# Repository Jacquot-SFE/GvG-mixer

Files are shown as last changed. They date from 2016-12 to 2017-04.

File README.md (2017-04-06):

The Gort Vs Goom IEM Mixer.
========================================



Read more about it in [my blog post](https://www.sparkfun.com/news/2352)

Repository Contents
-------------------

* **/Datasheets** - Data sheets for the ICs & other components.
* **/Eagle** - PCB files
* **/Spice** - Simulations of the baxandall and peak hold circuits.
* **/Block-diagram** - Poorly named.  Various vector art, including a block diagram, and panel files.

Documentation
----

Ideas mainly pulled from Doug Self's _Small Signal Audio Design_ book, with other input from datasheets and appnotes from THAT, Jensen, and Nat Semi.

License Information
-------------------

This product is _**open source**_!

Please review the LICENSE.md file for license information.

If you have any questions or concerns on licensing, please contact techsupport@sparkfun.com.

Distributed as-is; no warranty is given.

- Your friends at SparkFun.

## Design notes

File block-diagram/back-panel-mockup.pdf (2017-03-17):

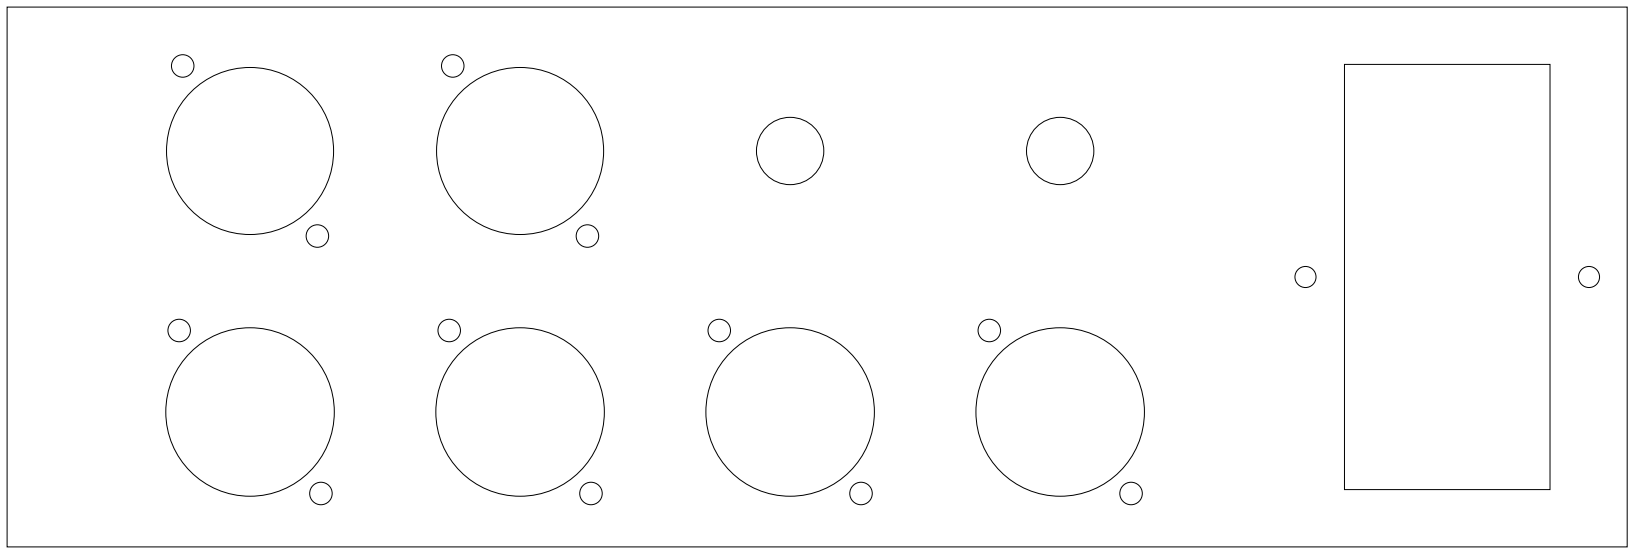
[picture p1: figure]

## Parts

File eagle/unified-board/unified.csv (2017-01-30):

Qty | MOUSER | Value | Device | Package | Parts | Description | MFR | PROD_ID | SF_ID | VALUE
14 | 505-MKS20.01/63/5 | 0.01uf | WIMA-MKS20.01UF | WIMA-MKS2-2.5X7.2 | C1, C2, C121, C122, C221, C222, C321, C322, C421, C422, C503, C504, C603, C604 |  |  |  |  | 0.01uf
8 | 80-C315C470J5G | 47pf | CAP-CERAMIC47PF | CAP-KEMET-GM-2.54LS | C101, C102, C201, C202, C301, C302, C401, C402 |  |  |  |  | 47pf
24 | 80-C315C471J1G | 470pf | CAP-CERAMIC470PF | CAP-KEMET-GM-2.54LS | C103, C104, C105, C106, C112, C113, C203, C204, C205, C206, C212, C213, C303, C304, C305, C306, C312, C313, C403, C404, C405, C406, C412, C413 |  |  |  |  | 470pf
8 | 667-EEU-FR1J470B | 47u/63V | CAP-LYTIC47U/63V | CAP-PANA-5LS-6DIAM | C107, C108, C207, C208, C307, C308, C407, C408 |  |  |  |  | 47u/63V
18 | 667-EEU-FR1E470B | 47u/25V | CAP-LYTIC47U/25V | CAP-PANA-5LS-5DIAM | C109, C110, C114, C120, C209, C210, C214, C220, C309, C310, C314, C320, C409, C410, C414, C420, C502, C602 |  |  |  |  | 47u/25V
4 | 667-EEU-FR1A682L | 6800u/25V | CAP-LYTIC6800U/10V | CAP-PANA-5LS-12.5DIAM | C111, C211, C311, C411 |  |  |  |  | 6800u/25V
8 | 505-MKS2.1/63/5 | 0.1uf | WIMA-MKS20.1UF | WIMA-MKS2-2.5X7.2 | C115, C116, C215, C216, C315, C316, C415, C416 |  |  |  |  | 0.1uf
8 | 505-MKS20.015/63/5 | 0.015uf | WIMA-MKS20.015UF | WIMA-MKS2-2.5X7.2 | C117, C118, C217, C218, C317, C318, C417, C418 |  |  |  |  | 0.015uf
8 | 80-C315C101J5G | 100pf | CAP-CERAMIC100PF | CAP-KEMET-GM-2.54LS | C119, C219, C319, C419, C501, C505, C601, C605 |  |  |  |  | 100pf
4 | 667-ECA-2CHG010 | 1uf/160V | CAP-LYTIC1UF/160V | CAP-PANA-2.5LS-6DIAM | C3, C4, C5, C6 |  |  |  |  | 1uf/160V
2 | 667-EEU-FR1V102 | 1000u/35V | CAP-LYTIC1000U/35V | CAP-PANA-5LS-12.5DIAM | C701, C702 |  |  |  |  | 1000u/35V
4 | sfe | 1n4148 | DIODE-1N4148 | DIODE-1N4148 | D1, D2, D3, D4 | Diode |  | DIO-08378 |  | 200mA/100V/1V
6 | 583-RB153 | RECTIFIERRB15X | RECTIFIERRB15X | SM-RECTIFIER | D101, D201, D301, D401, D501, D601
8 | sfe | 200mA/100V/1V | DIODE-1N4148 | DIODE-1N4148 | D102, D103, D202, D203, D302, D303, D402, D403 | Diode |  | DIO-08378 |  | 200mA/100V/1V
2 | sfe | RED | LED_BARGRAPH_10RED | LED_BARGRAPH_10 | D502, D602 | Young Sun LED Tech - YSLB-10251G5-10 10-Segment LED Bar Graph |  | DIO-10615 |  | RED
1 | sfe |  | LED5MM | LED_5MM | D701 | LED (Generic)
2 | 623-2743002112LF | FB | FB | BEAD | FB501, FB601 |  |  |  |  | FB
7 | na | FRAME-LEDGER | FRAME-LEDGER | CREATIVE_COMMONS | FRAME101, FRAME201, FRAME301, FRAME401, FRAME501, FRAME601, FRAME701 | Schematic Frame - Ledger
12 | na | STAND-OFF | STAND-OFF | STAND-OFF | H601, H602, H603, H604, H605, H606, H607, H608, H609, H610, H611, H612 | Stand Off
4 | 887-1512P08-U | THAT1512 | THAT151X | DIP08-KIT | IC101, IC201, IC301, IC401 |  |  |  |  | THAT1512
8 | na |  | M031X03_NO_SILK | 1X03_NO_SILK@1 | J101, J102, J201, J202, J301, J302, J401, J402 | Header 3
4 | na | phantom | M01NOSILK-KIT | 1X01NS-KIT | J103, J203, J303, J403 | Header 1
8 | na | eqout | M01NOSILK-KIT | 1X01NS-KIT | J104, J105, J204, J205, J304, J305, J404, J405 | Header 1
4 |  |  | CONN_05PTH_LONGPADS | 1X05_LONGPADS | J106, J206, J306, J406 | Multi connection point. Often used as Generic Header-pin footprint for 0.1 inch spaced/style header connections
2 |  | out2 | CONN_02LOCK_LONGPADS | 1X02_LOCK_LONGPADS | J501, J601 | Multi connection point. Often used as Generic Header-pin footprint for 0.1 inch spaced/style header connections
1 |  | power | CONN_03POLAR_LOCK | MOLEX-1X3_LOCK | J701 | Multi connection point. Often used as Generic Header-pin footprint for 0.1 inch spaced/style header connections |  | CONN-08625 | PRT-08096
14 |  | 10k | RESISTOR | AXIAL-0.3 | R1, R4, R501, R502, R503, R504, R505, R506, R601, R602, R603, R604, R605, R606
8 |  | 6k8 | RESISTOR | AXIAL-0.3 | R101, R102, R201, R202, R301, R302, R401, R402
8 |  | 10 | RESISTOR | AXIAL-0.3 | R103, R104, R203, R204, R303, R304, R403, R404
8 |  | 4k99 | RESISTOR | AXIAL-0.3 | R105, R106, R205, R206, R305, R306, R405, R406
4 |  | 22k | RESISTOR | AXIAL-0.3 | R107, R207, R307, R407
8 |  | 1k2 | RESISTOR | AXIAL-0.3 | R108, R109, R208, R209, R308, R309, R408, R409
4 |  | 5 | RESISTOR | AXIAL-0.3 | R110, R210, R310, R410
8 |  | 1k8 | RESISTOR | AXIAL-0.3 | R111, R112, R211, R212, R311, R312, R411, R412
4 |  | 12k | RESISTOR | AXIAL-0.3 | R113, R213, R313, R413
2 |  | 100k | RESISTOR | AXIAL-0.3 | R2, R5
14 |  | 1k | RESISTOR | AXIAL-0.3 | R3, R6, R114, R115, R116, R214, R215, R216, R314, R315, R316, R414, R415, R416
2 |  | 100 | RESISTOR | AXIAL-0.3 | R507, R607
2 |  | 47k | RESISTOR | AXIAL-0.3 | R508, R608
6 |  | ??? | RESISTOR | AXIAL-0.3 | R509, R510, R511, R609, R610, R611
2 |  | 10 | RESISTORAXIAL-0.3 | AXIAL-0.3 | R701, R702 | Resistor
1 |  | 1k5 | RESISTORAXIAL-0.3 | AXIAL-0.3 | R703 | Resistor
1 | sfe | LM358 | LM358 | DIP08 | U1 | LM358 |  | IC-09172 |  | LM358
6 | 926-LME49710NA/NOPB | lme49710 | OPAMPLME49710 | DIP08-KIT | U101, U201, U301, U401, U501, U601 |  | lme49710 |  |  | lme49710
2 | sfe | LM3915N | LM3915N | DIL18 | U502, U602 | LM3914 Dot/Bar Display Driver
4 | sfe | 10K | POTROT-SW-POT | ROT-SW-POT | VR101, VR201, VR301, VR401
8 | 31VQ401-F3 | 10K | POT10K-VERTPIN | ALPHA-RV24AF40-POT | VR102, VR103, VR104, VR105, VR202, VR203, VR204, VR205, VR302, VR303, VR304, VR305, VR402, VR403, VR404, VR405 |  |  |  |  | 10K
8 | 31vj401-f3

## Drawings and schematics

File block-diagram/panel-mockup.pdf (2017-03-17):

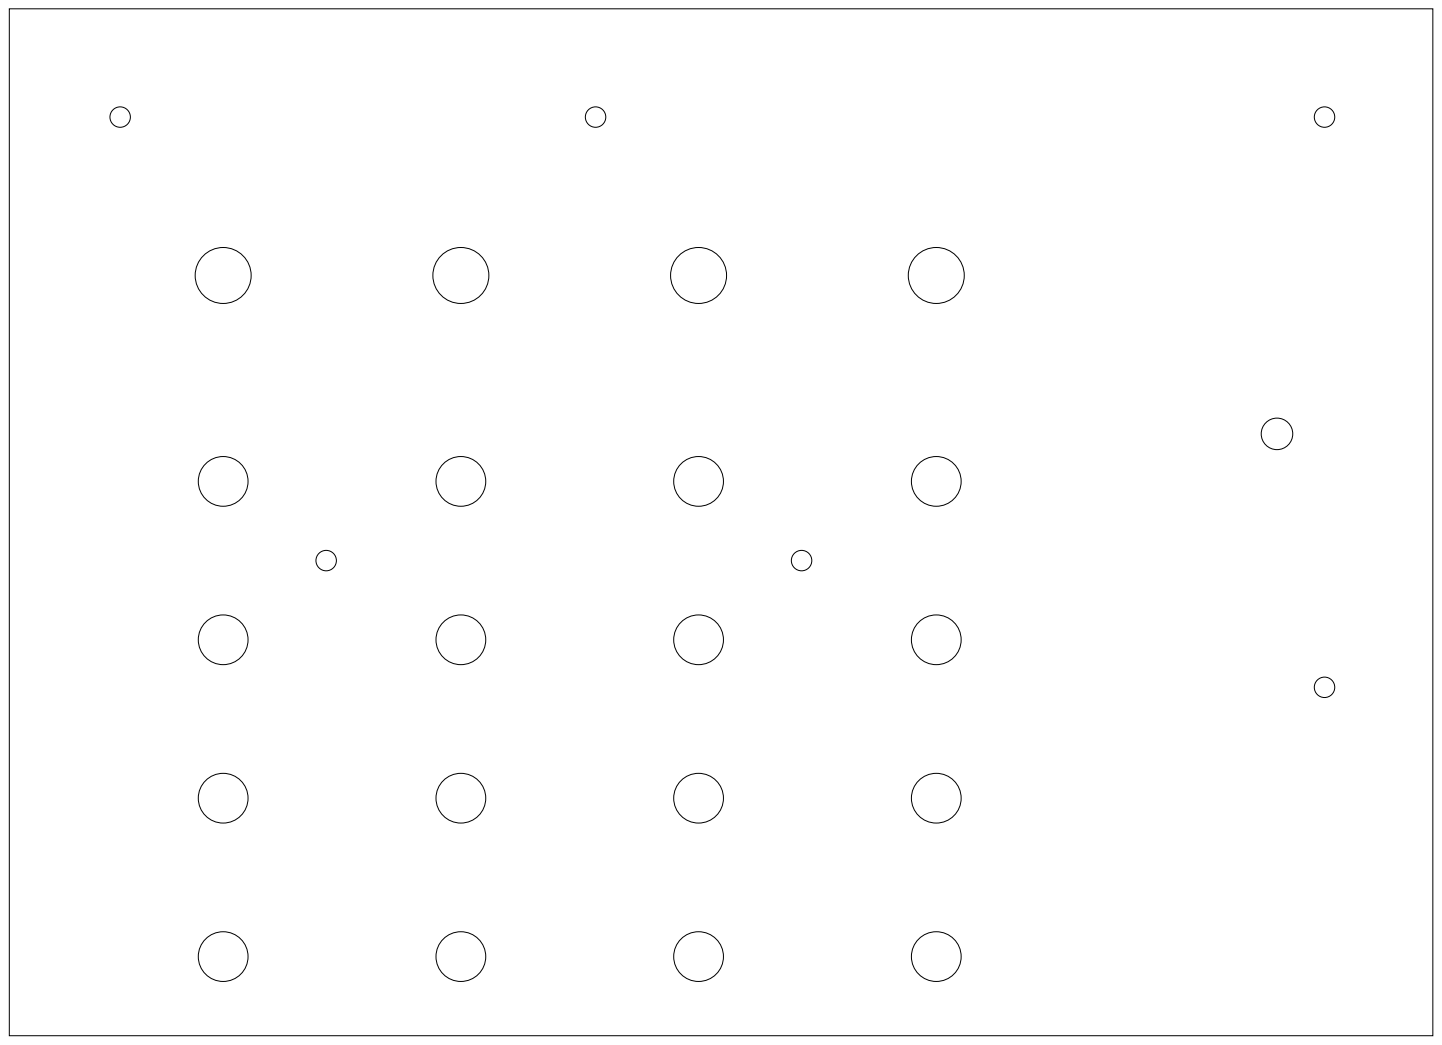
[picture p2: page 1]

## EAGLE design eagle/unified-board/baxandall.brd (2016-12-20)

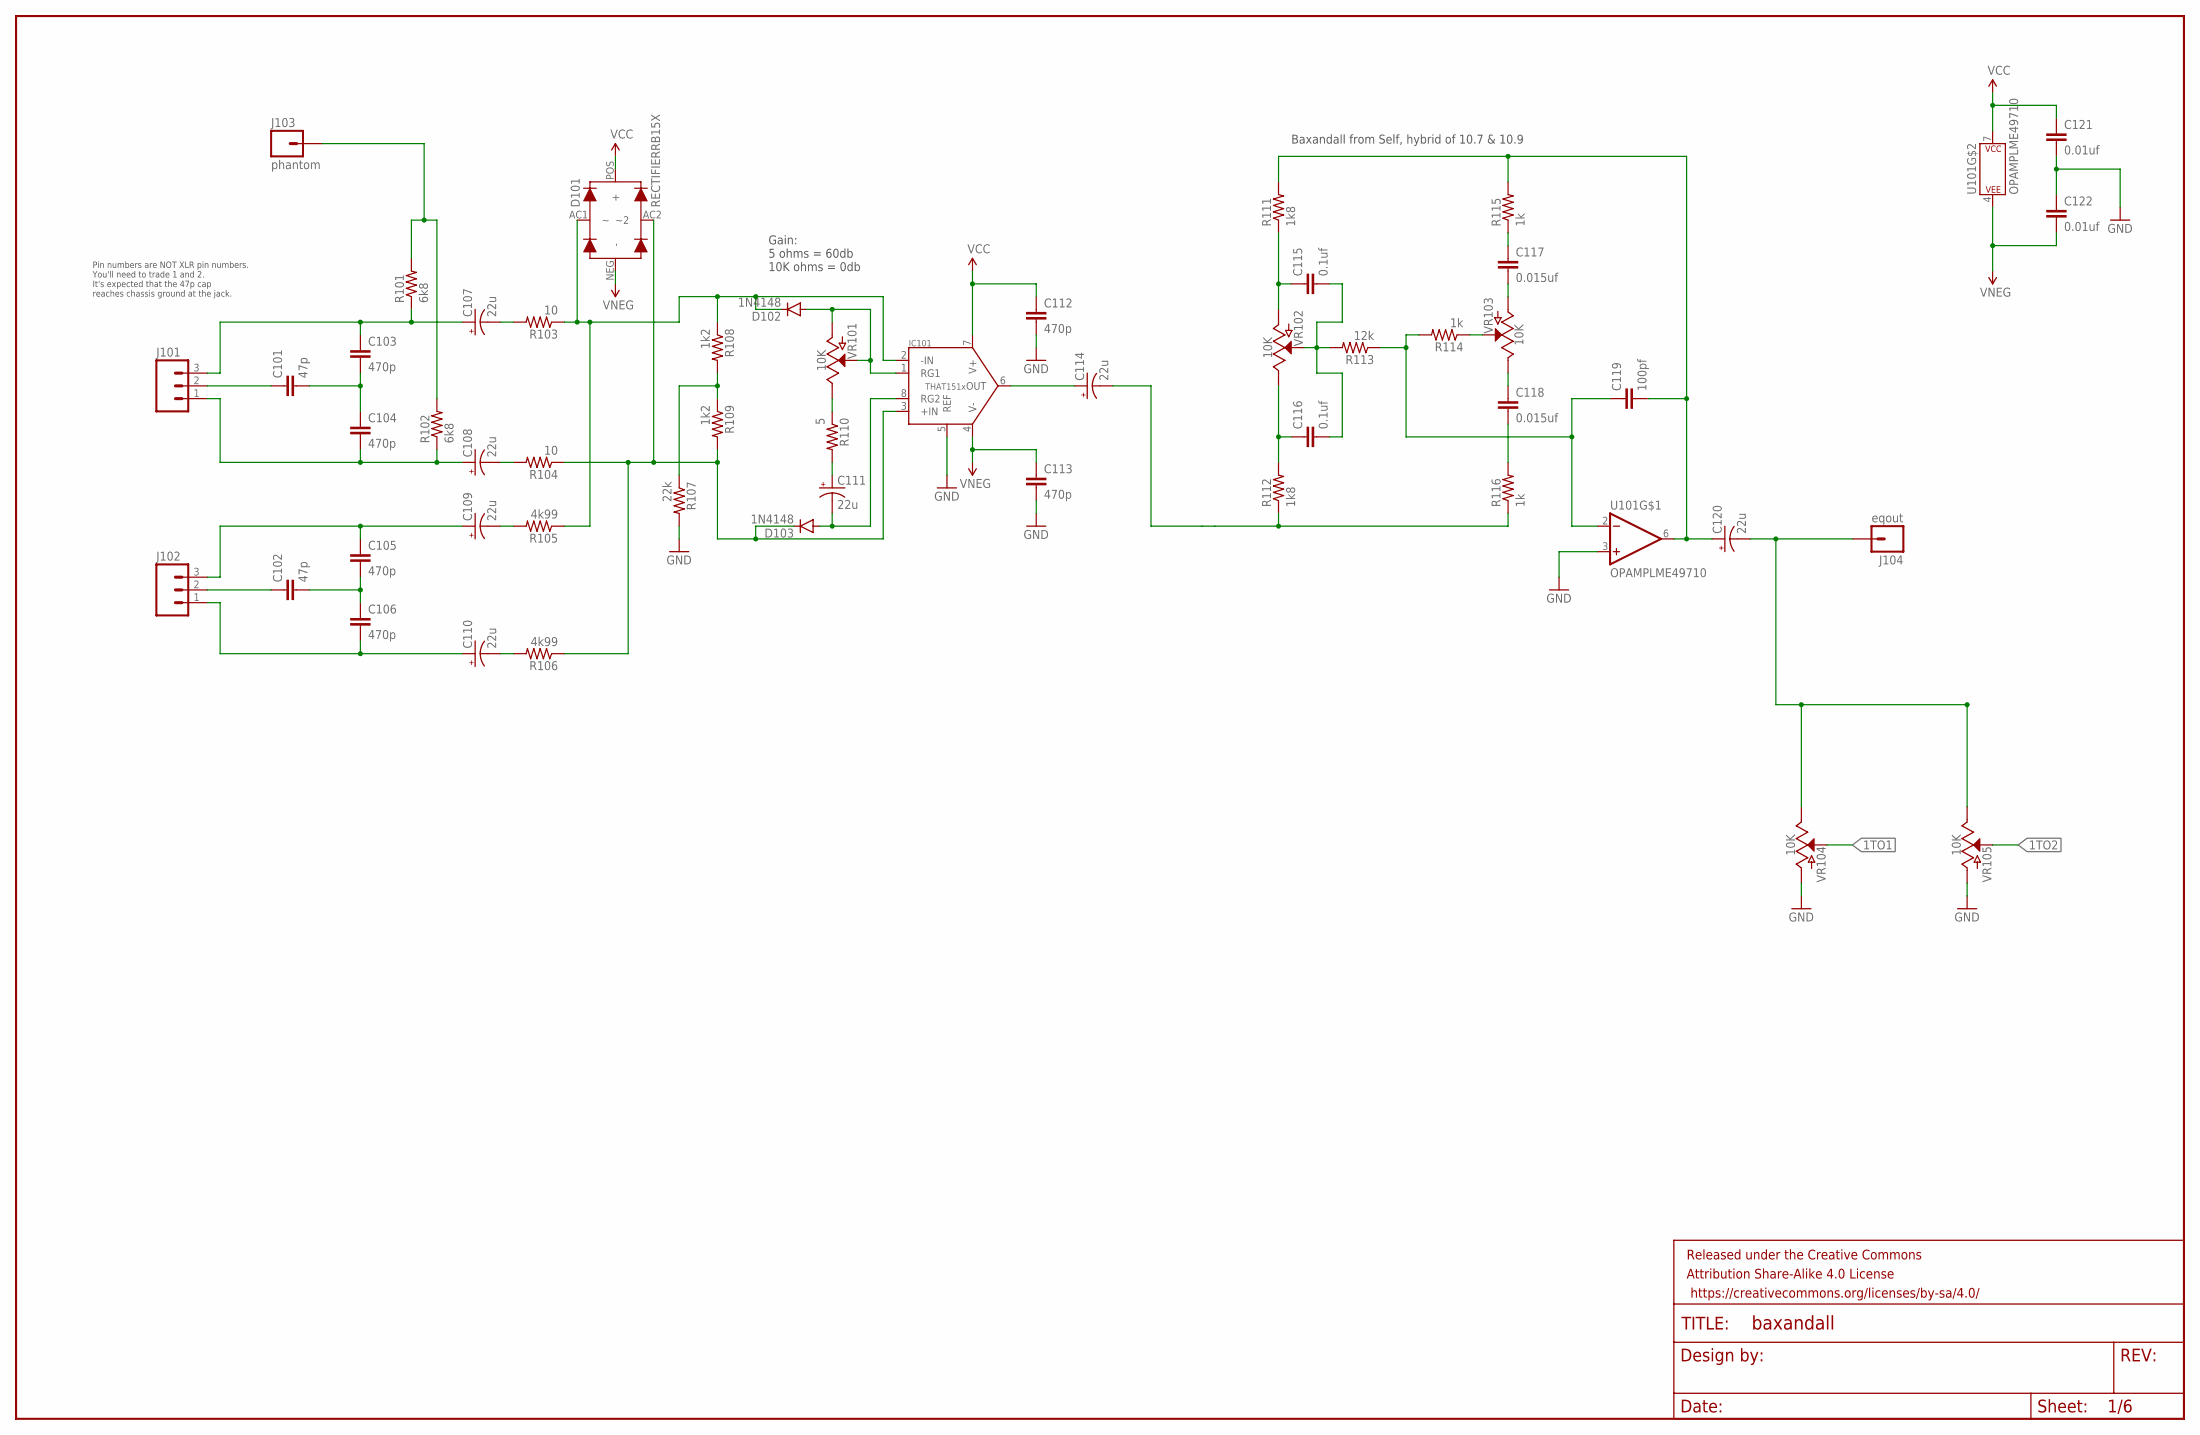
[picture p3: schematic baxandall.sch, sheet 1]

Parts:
C101, C102: 47p; CAP-PTH-SMALL
C103, C104, C105, C106, C112, C113: 470p; CAP-PTH-SMALL
C107, C108, C109, C110, C111, C114, C120: 22u; CPOL-RADIAL-100UF-25V
C115, C116: 0.1uf; WIMA-MKS2-2.5X7.2
C117, C118: 0.015uf; WIMA-MKS2-2.5X7.2
C119: 100pf; CAP-PTH-SMALL
C121, C122: 0.01uf; WIMA-MKS2-2.5X7.2
D101: RECTIFIERRB15X; SM-RECTIFIER
D102, D103: 1N4148; DIODE-1N4148
FRAME101: FRAME-LEDGER; CREATIVE_COMMONS
IC101: THAT151x; DIP08-KIT
J101, J102: M031X03_NO_SILK; 1X03_NO_SILK
J103: phantom; 1X01NS-KIT
J104: eqout; 1X01NS-KIT
R101, R102: 6k8; AXIAL-0.3
R103, R104: 10; AXIAL-0.3
R105, R106: 4k99; AXIAL-0.3
R107: 22k; AXIAL-0.3
R108, R109: 1k2; AXIAL-0.3
R110: 5; AXIAL-0.3
R111, R112: 1k8; AXIAL-0.3
R113: 12k; AXIAL-0.3
R114, R115, R116: 1k; AXIAL-0.3
U101: OPAMPLME49710; DIP08-KIT
VR101: 10K; ROT-SW-POT
VR102, VR103, VR104, VR105: 10K; ALPHA-RV24AF40-POT

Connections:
1TO1: VR104.WIP (S)
1TO2: VR105.WIP (S); also elsewhere on the board
GND: C112.2, C113.2, C121.P$2 (2), C122.P$1 (1), IC101.5 (REF), R107.P$2 (2), U101.3 (+IN), VR104.CCW (A), VR105.CCW (A); also elsewhere on the board
unnamed: C115.P$1 (1), R111.P$1 (1), VR102.CCW (A)
unnamed: C116.P$1 (1), R112.P$2 (2), VR102.CW (E)
unnamed: C119.1, R113.P$1 (1), R114.P$2 (2), U101.2 (-IN)
unnamed: C118.P$2 (2), R116.P$2 (2)
unnamed: C120.2 (-), J104.1, VR104.CW (E), VR105.CW (E)
unnamed: C119.2, C120.1 (+), R111.P$2 (2), R115.P$2 (2), U101.6 (OUT)
unnamed: R114.P$1 (1), VR103.WIP (S)
unnamed: C114.2 (-), R112.P$1 (1), R116.P$1 (1)
unnamed: C118.P$1 (1), VR103.CW (E)
unnamed: C115.P$2 (2), C116.P$2 (2), R113.P$2 (2), VR102.WIP (S)
unnamed: C117.P$2 (2), VR103.CCW (A)
unnamed: C117.P$1 (1), R115.P$1 (1)
unnamed: C111.2 (-), D103.A, IC101.8 (RG2)
unnamed: C114.1 (+), IC101.6 (OUT)
unnamed: C101.1, J101.2
unnamed: C101.2, C103.2, C104.1
unnamed: C103.1, C107.1 (+), J101.3, R101.P$1 (1)
unnamed: C104.2, C108.1 (+), J101.1, R102.P$1 (1)
unnamed: C108.2 (-), R104.P$2 (2)
unnamed: J103.1, R101.P$2 (2), R102.P$2 (2)
unnamed: C107.2 (-), R103.P$2 (2)
unnamed: D101.AC1, D102.C, IC101.2 (-IN), R103.P$1 (1), R105.P$1 (1), R108.P$1 (1)
unnamed: D101.AC2 (~2), D103.C, IC101.3 (+IN), R104.P$1 (1), R106.P$1 (1), R109.P$2 (2)
unnamed: R107.P$1 (1), R108.P$2 (2), R109.P$1 (1)
unnamed: D102.A, IC101.1 (RG1), VR101.CCW (A), VR101.WIP (S)
unnamed: R110.P$1 (1), VR101.CW (E)
unnamed: C111.1 (+), R110.P$2 (2)
unnamed: C102.1, J102.2
unnamed: C102.2, C105.2, C106.1
unnamed: C105.1, C109.1 (+), J102.3
unnamed: C106.2, C110.1 (+), J102.1
unnamed: C110.2 (-), R106.P$2 (2)
unnamed: C109.2 (-), R105.P$2 (2)
VCC: C112.1, C121.P$1 (1), D101.POS (+), IC101.7 (V+), U101.7 (P$V+); also elsewhere on the board
VNEG: C113.1, C122.P$2 (2), D101.NEG (-), IC101.4 (V-), U101.4 (P$V-); also elsewhere on the board

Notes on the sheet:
Pin numbers are NOT XLR pin numbers. You'll need to trade 1 and 2. It's expected that the 47p cap reaches chassis ground at the jack.
Baxandall from Self, hybrid of 10.7 & 10.9
Gain: 5 ohms = 60db 10K ohms = 0db

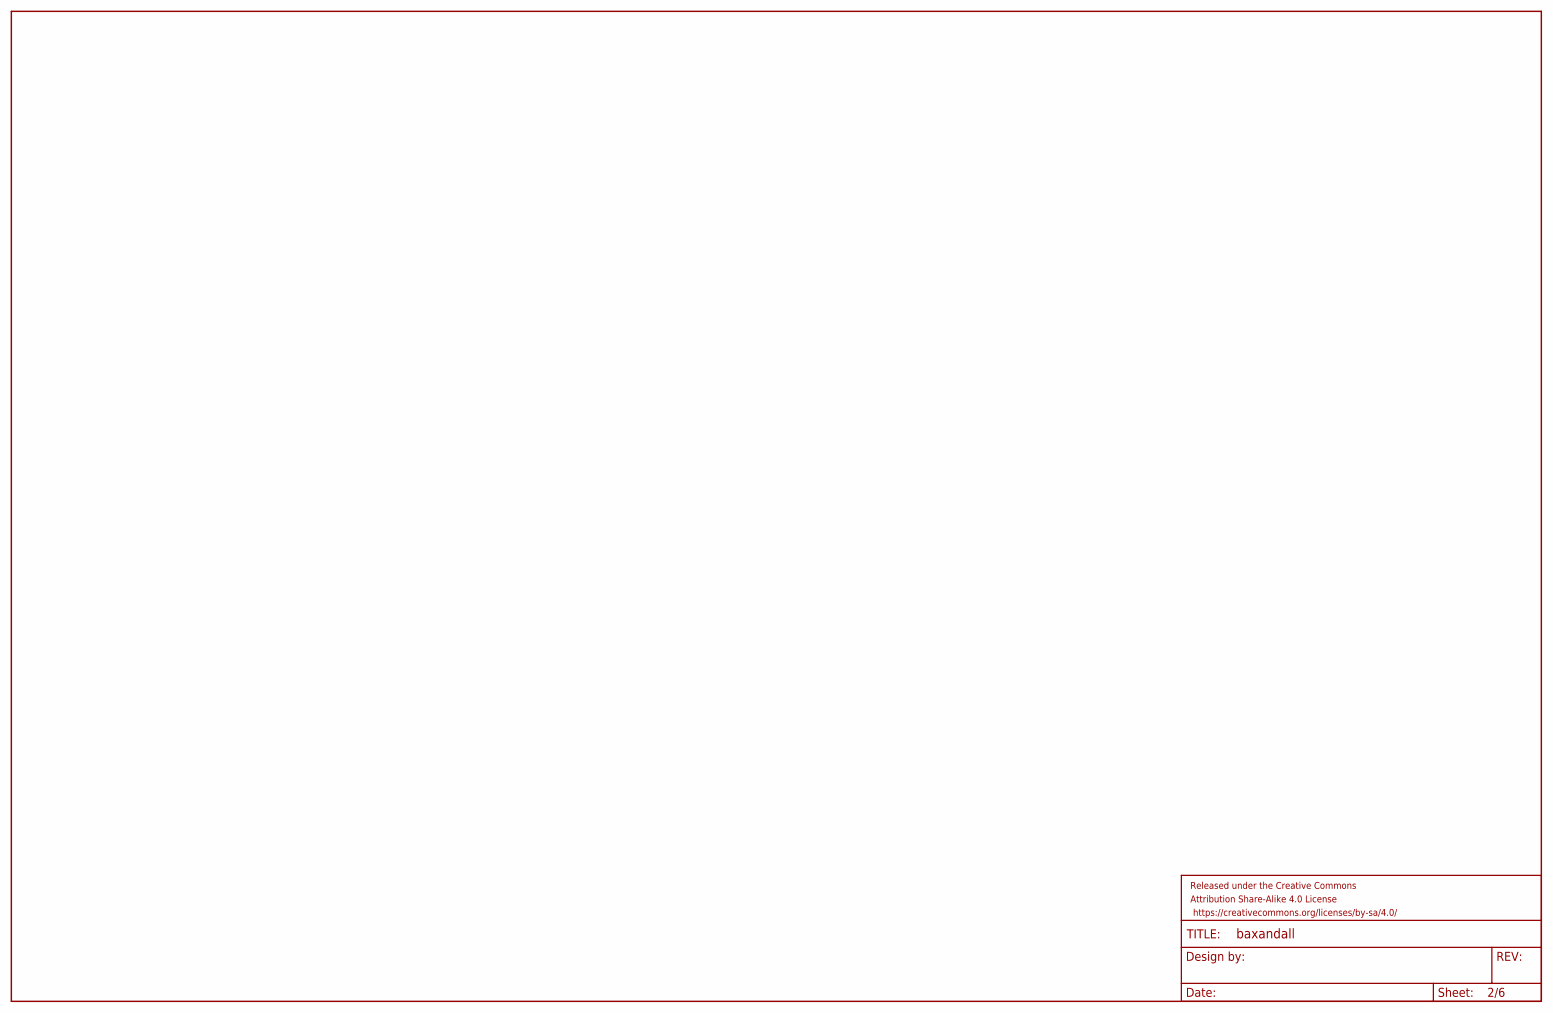
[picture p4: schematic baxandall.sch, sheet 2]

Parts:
FRAME201: FRAME-LEDGER; CREATIVE_COMMONS

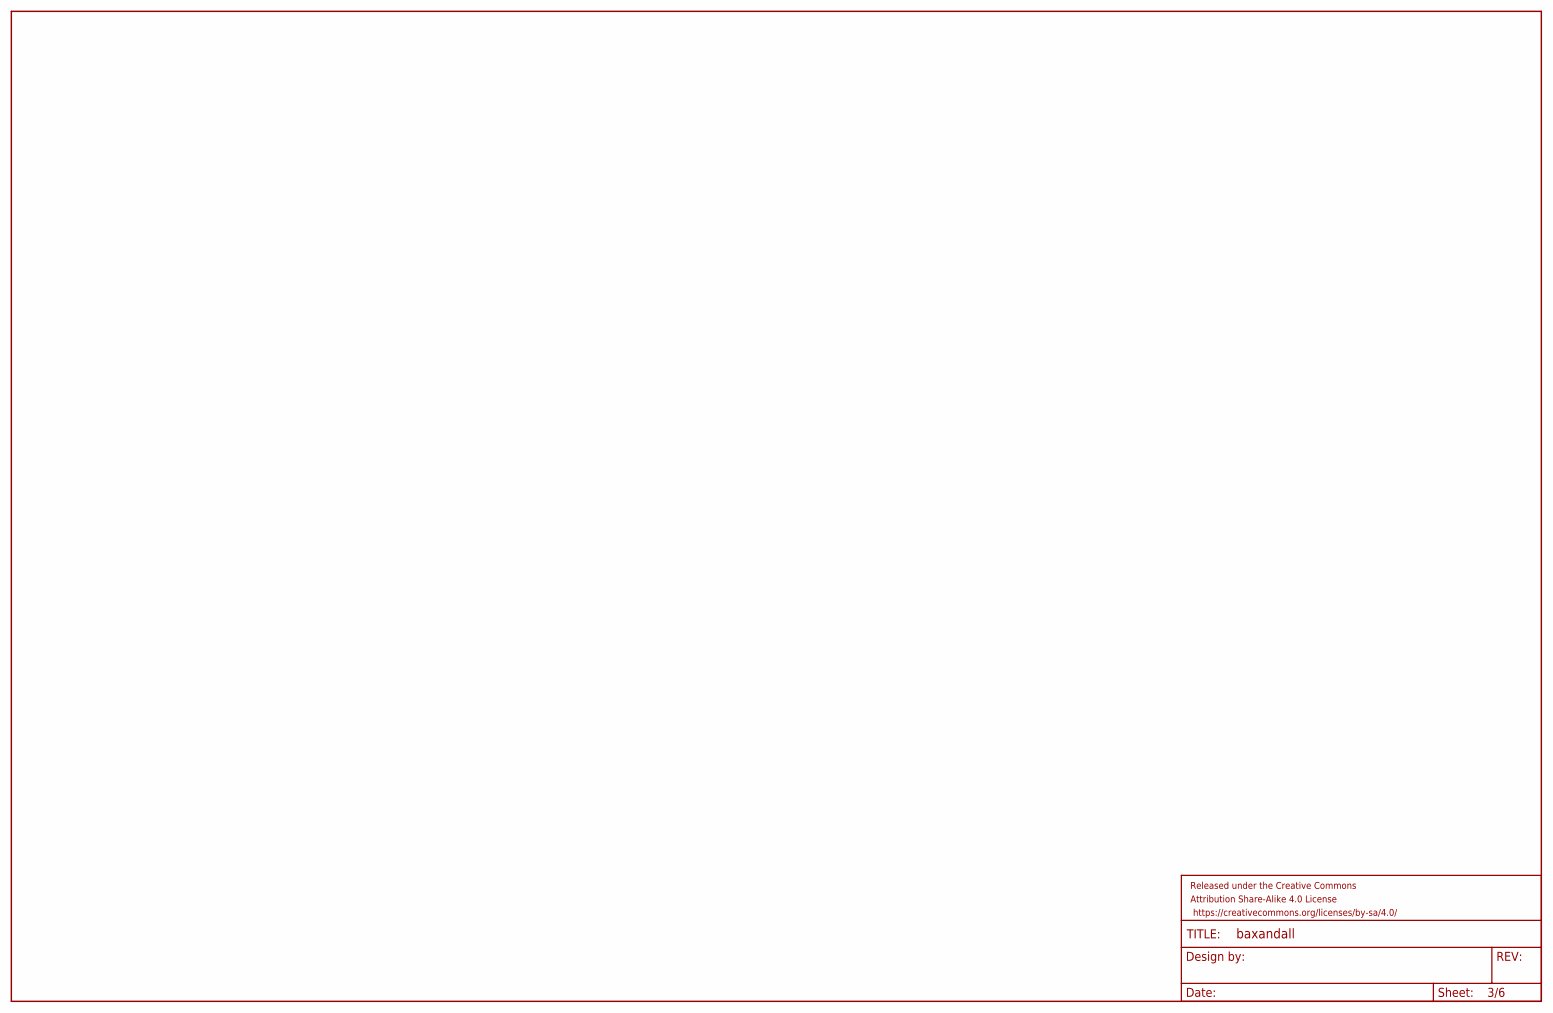
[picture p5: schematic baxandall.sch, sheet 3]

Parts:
FRAME301: FRAME-LEDGER; CREATIVE_COMMONS

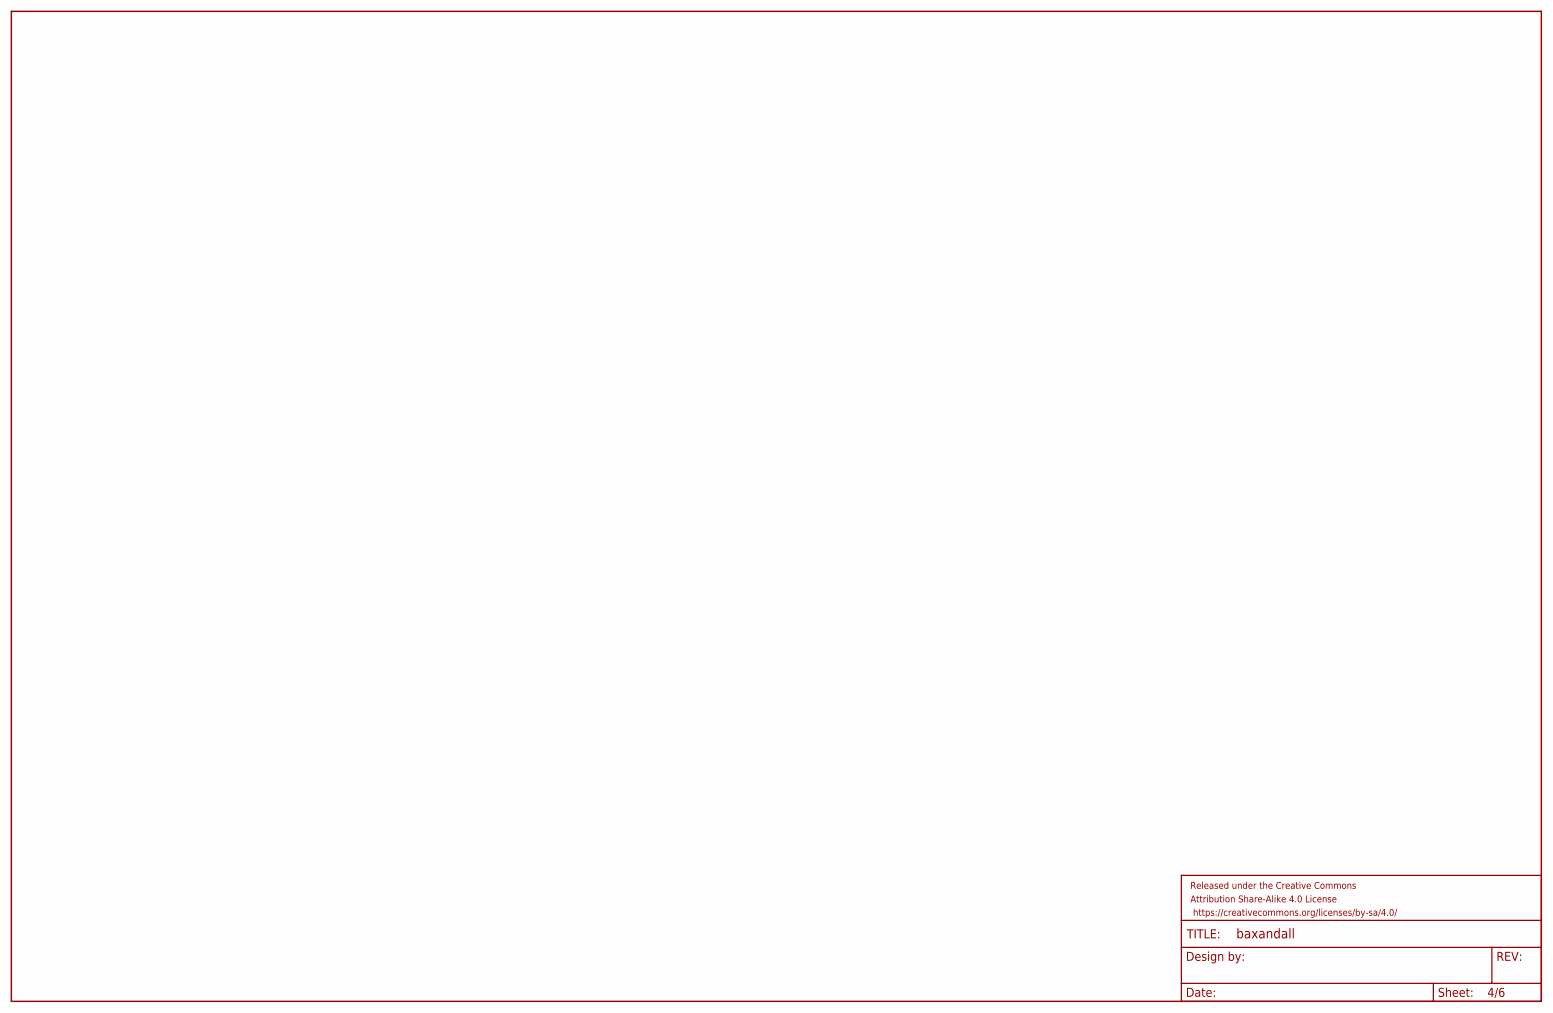
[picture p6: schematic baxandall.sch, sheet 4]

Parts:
FRAME401: FRAME-LEDGER; CREATIVE_COMMONS

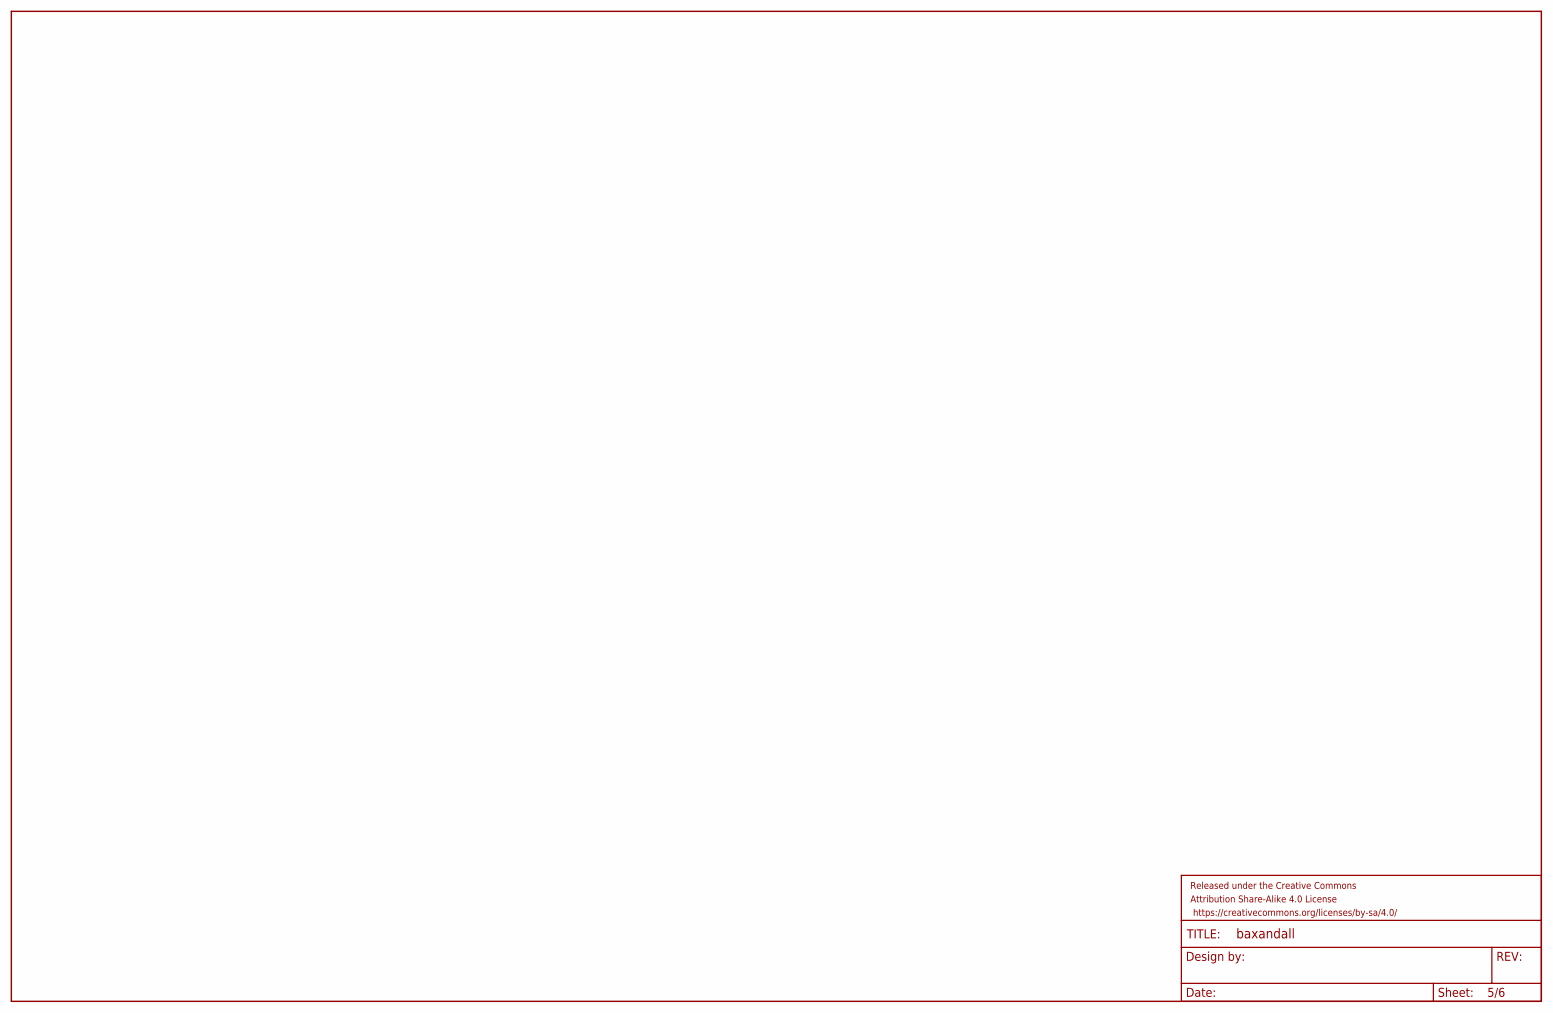
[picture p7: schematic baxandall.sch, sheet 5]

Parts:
FRAME501: FRAME-LEDGER; CREATIVE_COMMONS

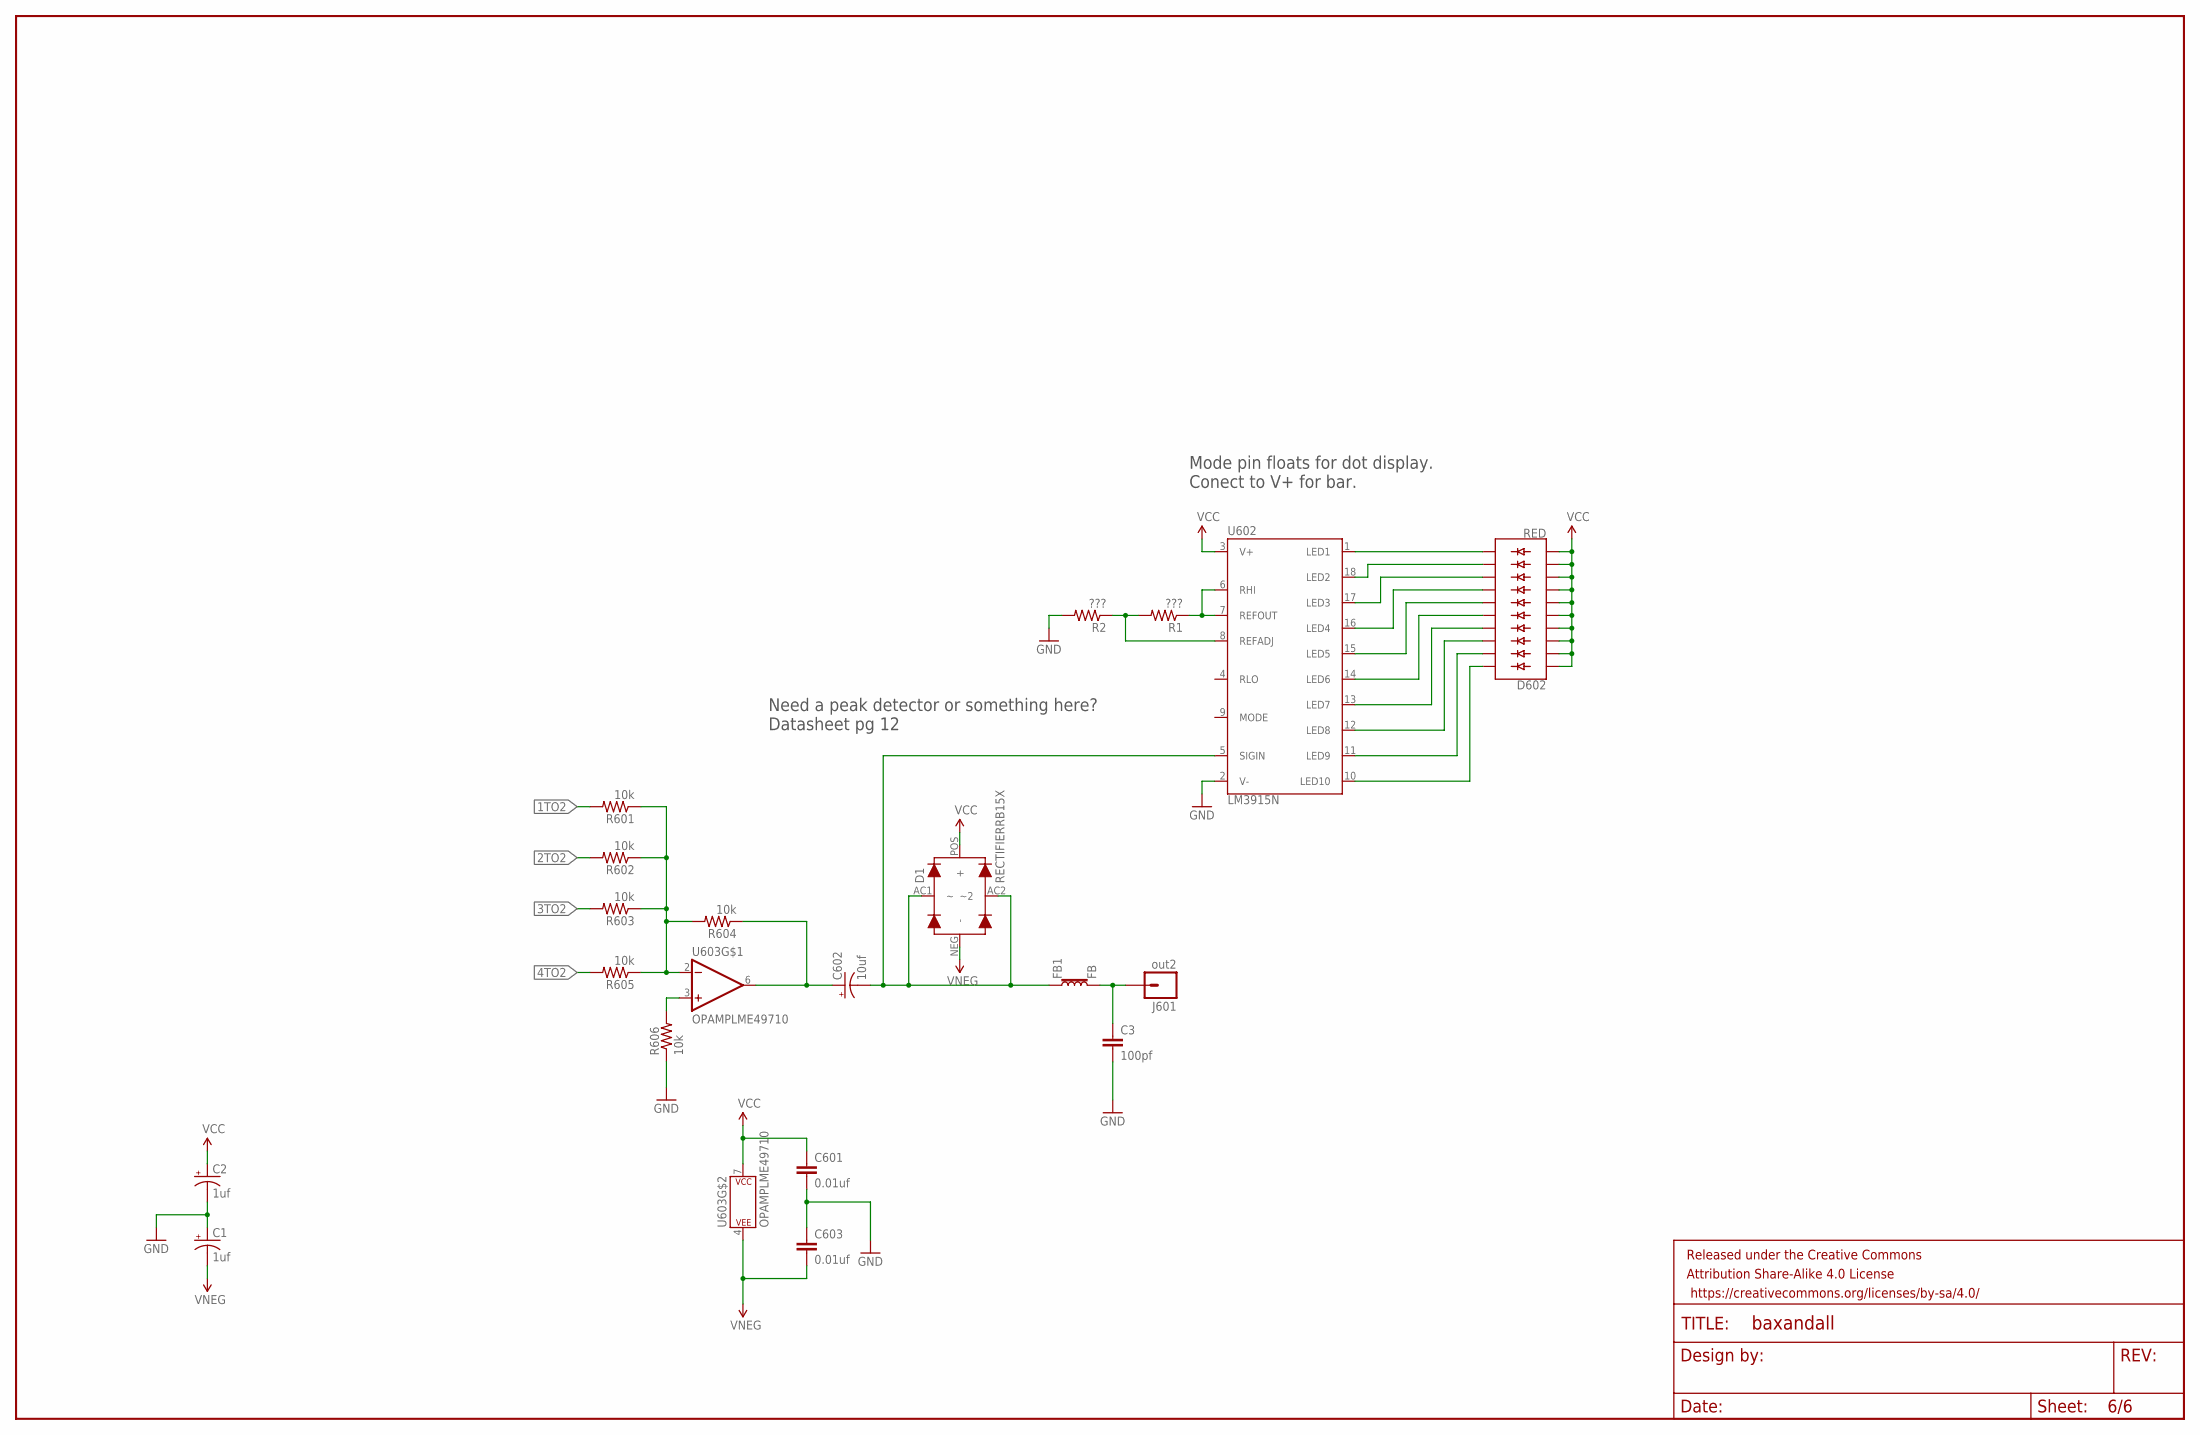
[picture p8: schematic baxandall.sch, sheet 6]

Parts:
C1, C2: 1uf; CPOL-RADIAL-10UF-25V
C3: 100pf; CAP-PTH-SMALL
C601, C603: 0.01uf; WIMA-MKS2-2.5X7.2
C602: 10uf; CPOL-RADIAL-10UF-25V
D1: RECTIFIERRB15X; SM-RECTIFIER
D602: RED; LED_BARGRAPH_10
FB1: FB; BEAD
FRAME601: FRAME-LEDGER; CREATIVE_COMMONS
J601: out2; 1X01NS-KIT
R1, R2: ???; AXIAL-0.3
R601, R602, R603, R604, R605, R606: 10k; AXIAL-0.3
U602: LM3915N; DIL18
U603: OPAMPLME49710; DIP08-KIT

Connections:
1TO2: R601.P$2 (2); also elsewhere on the board
2TO2: R602.P$2 (2)
3TO2: R603.P$2 (2)
4TO2: R605.P$2 (2)
GND: C1.1 (+), C2.2 (-), C3.2, C601.P$2 (2), C603.P$1 (1), R2.P$2 (2), R606.P$1 (1), U602.2 (V-); also elsewhere on the board
unnamed: C3.1, FB1.P$2 (2), J601.1
unnamed: C602.2 (-), D1.AC1, D1.AC2 (~2), FB1.P$1 (1), U602.5 (SIGIN)
unnamed: R606.P$2 (2), U603.3 (+IN)
unnamed: C602.1 (+), R604.P$1 (1), U603.6 (OUT)
unnamed: R601.P$1 (1), R602.P$1 (1), R603.P$1 (1), R604.P$2 (2), R605.P$1 (1), U603.2 (-IN)
unnamed: D602.11 (C9), U602.1 (LED1)
unnamed: D602.12 (C8), U602.18 (LED2)
unnamed: D602.13 (C7), U602.17 (LED3)
unnamed: D602.14 (C6), U602.16 (LED4)
unnamed: D602.15 (C5), U602.15 (LED5)
unnamed: D602.16 (C4), U602.14 (LED6)
unnamed: D602.17 (C3), U602.13 (LED7)
unnamed: D602.18 (C2), U602.12 (LED8)
unnamed: D602.19 (C1), U602.11 (LED9)
unnamed: D602.20 (C), U602.10 (LED10)
unnamed: R1.P$1 (1), U602.6 (RHI), U602.7 (REFOUT)
unnamed: R1.P$2 (2), R2.P$1 (1), U602.8 (REFADJ)
VCC: C2.1 (+), C601.P$1 (1), D1.POS (+), D602.1 (A), D602.2 (A1), D602.3 (A2), D602.4 (A3), D602.5 (A4), D602.6 (A5), D602.7 (A6), D602.8 (A7), D602.9 (A8), D602.10 (A9), U602.3 (V+), U603.7 (P$V+); also elsewhere on the board
VNEG: C1.2 (-), C603.P$2 (2), D1.NEG (-), U603.4 (P$V-); also elsewhere on the board

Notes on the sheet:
Need a peak detector or something here? Datasheet pg 12
Mode pin floats for dot display. Conect to V+ for bar.

Board: 2 copper layers, 78 parts (0 on the bottom side), 54 nets, no tracks yet.

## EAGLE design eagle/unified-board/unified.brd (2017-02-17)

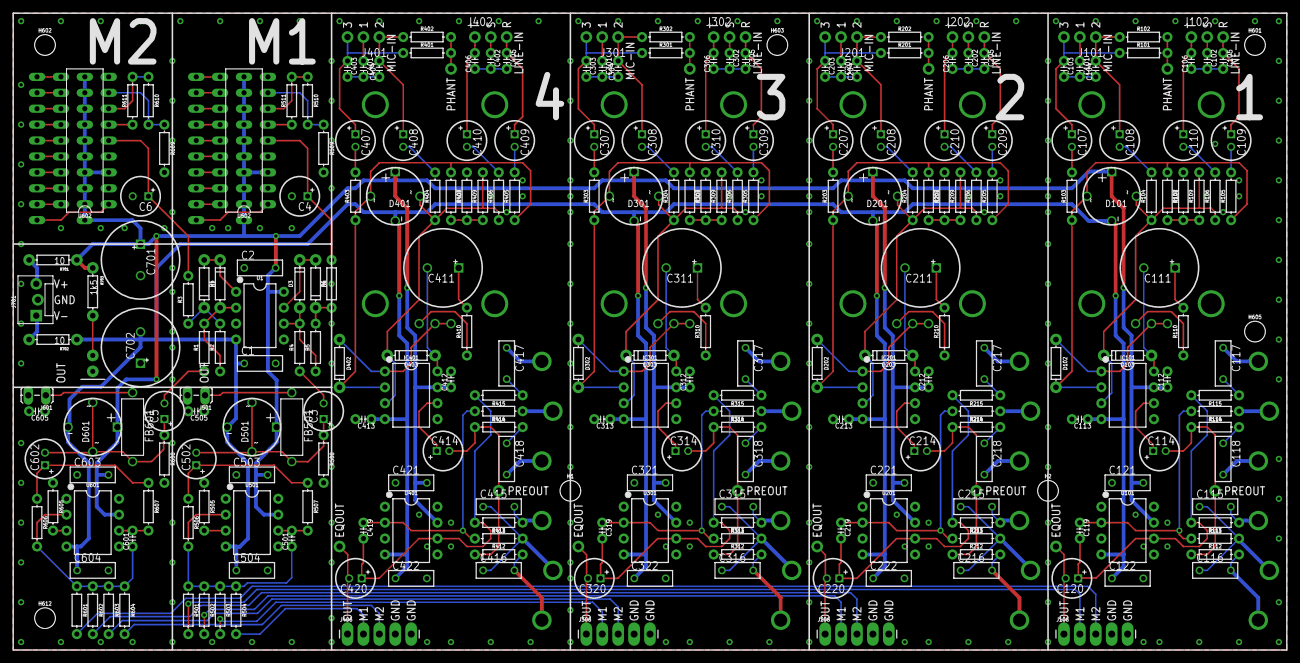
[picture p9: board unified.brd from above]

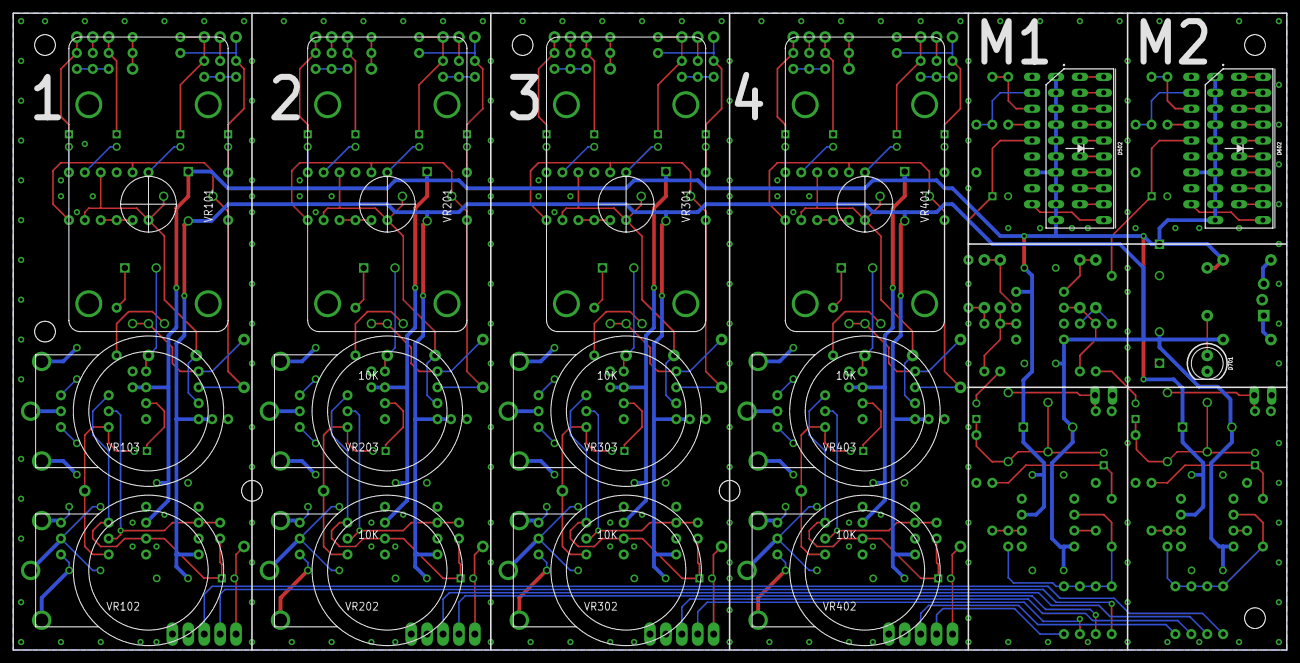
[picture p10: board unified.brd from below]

Board: 2 copper layers, 203.2 x 101.6 mm, 290 parts (15 on the bottom side), 194 nets.

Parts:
C1, C2, C121, C122, C221, C222, C321, C322, C421, C422, C503, C504, C603, C604: 0.01uf; WIMA-MKS2-2.5X7.2
C3, C4, C5, C6: 1uf/160V; CAP-PANA-2.5LS-6DIAM
C101, C102, C201, C202, C301, C302, C401, C402: 47pf; CAP-KEMET-GM-2.54LS
C103, C104, C105, C106, C112, C113, C203, C204, C205, C206, C212, C213, C303, C304, C305, C306, C312, C313, C403, C404, C405, C406, C412, C413: 470pf; CAP-KEMET-GM-2.54LS
C107, C108, C207, C208, C307, C308, C407, C408: 47u/63V; CAP-PANA-2LS-6DIAM
C109, C110, C114, C120, C209, C210, C214, C220, C309, C310, C314, C320, C409, C410, C414, C420, C502, C602: 47u/25V; CAP-PANA-2LS-5DIAM
C111, C211, C311, C411: 6800u/25V; CAP-PANA-5LS-12.5DIAM
C115, C116, C215, C216, C315, C316, C415, C416: 0.1uf; WIMA-MKS2-2.5X7.2
C117, C118, C217, C218, C317, C318, C417, C418: 0.015uf; WIMA-MKS2-2.5X7.2
C119, C219, C319, C419, C501, C505, C601, C605: 100pf; CAP-KEMET-GM-2.54LS
C701, C702: 1000u/35V; CAP-PANA-5LS-12.5DIAM
D1, D2, D3, D4: 1n4148; DIODE-1N4148
D101, D201, D301, D401, D501, D601: RECTIFIERRB15X; SM-RECTIFIER
D102, D103, D202, D203, D302, D303, D402, D403: 200mA/100V/1V; DIODE-1N4148
D502, D602: RED; LED_BARGRAPH_10
D701: LED_5MM
FB501, FB601: FB; BEAD
FRAME101, FRAME201, FRAME301, FRAME401, FRAME501, FRAME601, FRAME701: FRAME-LEDGER; CREATIVE_COMMONS
H1, H2, H601, H602, H603, H605, H612: STAND-OFF
IC101, IC201, IC301, IC401: THAT1512; DIP08-KIT
J101, J102, J201, J202, J301, J302, J401, J402: 1X03_NO_SILK@1
J103, J203, J303, J403: phantom; 1X01NS-KIT
J104, J105, J204, J205, J304, J305, J404, J405: eqout; 1X01NS-KIT
J106, J206, J306, J406: 1X05_LONGPADS
J501, J601: out2; 1X02_LOCK_LONGPADS
J701: power; MOLEX-1X3_LOCK
R1, R4, R501, R502, R503, R504, R505, R506, R601, R602, R603, R604, R605, R606: 10k; AXIAL-0.3
R2, R5: 100k; AXIAL-0.3
R3, R6, R114, R115, R116, R214, R215, R216, R314, R315, R316, R414, R415, R416: 1k; AXIAL-0.3
R101, R102, R201, R202, R301, R302, R401, R402: 6k8; AXIAL-0.3
R103, R104, R203, R204, R303, R304, R403, R404, R701, R702: 10; AXIAL-0.3
R105, R106, R205, R206, R305, R306, R405, R406: 4k99; AXIAL-0.3
R107, R207, R307, R407: 22k; AXIAL-0.3
R108, R109, R208, R209, R308, R309, R408, R409: 1k2; AXIAL-0.3
R110, R210, R310, R410: 5; AXIAL-0.3
R111, R112, R211, R212, R311, R312, R411, R412: 1k8; AXIAL-0.3
R113, R213, R313, R413: 12k; AXIAL-0.3
R507, R607: 100; AXIAL-0.3
R508, R608: 47k; AXIAL-0.3
R509, R510, R511, R609, R610, R611: ???; AXIAL-0.3
R703: 1k5; AXIAL-0.3
U1: LM358; DIP08
U101, U201, U301, U401, U501, U601: lme49710; DIP08-KIT
U502, U602: LM3915N; DIL18
VR101, VR201, VR301, VR401: 10K; ROT-SW-POT
VR102, VR103, VR202, VR203, VR302, VR303, VR402, VR403: 10K; ALPHA-RV24AF40-POT

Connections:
1TO1: J106.2, R501.P$2
1TO2: J106.3, R601.P$2
2TO1: J206.2, R502.P$2
2TO2: J206.3, R602.P$2
3TO1: J306.2, R503.P$2
3TO2: J306.3, R603.P$2
4TO1: J406.2, R504.P$2
4TO2: J406.3, R604.P$2
EQ1OUT: C120.NEG, J105.1, J106.1
EQ2OUT: C220.NEG, J205.1, J206.1
EQ3OUT: C320.NEG, J305.1, J306.1
EQ4OUT: C420.NEG, J405.1, J406.1
GND: C1.P$1, C2.P$2, C4.NEG, C6.NEG, C112.P$2, C113.P$2, C121.P$2, C122.P$1, C212.P$2, C213.P$2, C221.P$2, C222.P$1, C312.P$2, C313.P$2, C321.P$2, C322.P$1, C412.P$2, C413.P$2, C421.P$2, C422.P$1, C503.P$2, C504.P$1, C505.P$2, C603.P$2, C604.P$1, C605.P$2, C701.NEG, C702.POS, D701.K, IC101.5, IC201.5, IC301.5, IC401.5, J106.4, J106.5, J206.4, J206.5, J306.4, J306.5, J406.4, J406.5, J501.2, J601.2, J701.2, R107.P$2, R207.P$2, R307.P$2, R407.P$2, R505.P$1, R508.P$2, R509.P$2, R605.P$1, R608.P$2, R609.P$2, U1.3, U1.5, U101.3, U201.3, U301.3, U401.3, U502.2, U502.4, U602.2, U602.4
HIGHEST: D602.20, U602.10
HIGHEST1: D502.20, U502.10
L1+: C106.P$2, C110.POS, J102.1
L1-: C105.P$1, C109.POS, J102.3
L1GND: C102.P$1, J102.2
LOWEST: D602.11, U602.1
LOWEST1: D502.11, U502.1
M1+: C104.P$2, C108.POS, J101.1, R102.P$1
M1-: C103.P$1, C107.POS, J101.3, R101.P$1
M1GND: C101.P$1, J101.2
unnamed: C115.P$1, R111.P$1, VR102.CCW
unnamed: C116.P$1, R112.P$2, VR102.CW
unnamed: C119.P$1, R113.P$1, R114.P$2, U101.2
unnamed: C118.P$2, R116.P$2
unnamed: D1.A, R1.P$2, R2.P$1, U1.2
unnamed: C119.P$2, C120.POS, R111.P$2, R115.P$2, U101.6
unnamed: C605.P$1, FB601.P$2, J601.1
unnamed: R114.P$1, VR103.WIP
unnamed: D1.C, D2.A, U1.1
unnamed: C118.P$1, VR103.CW
unnamed: C5.POS, C602.NEG, D601.AC1, D601.AC2, FB601.P$1, R608.P$1
unnamed: C602.POS, R606.P$1, R607.P$1
unnamed: R605.P$2, U601.3
unnamed: C115.P$2, C116.P$2, R113.P$2, VR102.WIP
unnamed: C117.P$2, VR103.CCW
unnamed: C601.P$2, R607.P$2, U601.6
unnamed: C601.P$1, R601.P$1, R602.P$1, R603.P$1, R604.P$1, R606.P$2, U601.2
unnamed: D2.C, R2.P$2, R3.P$1
unnamed: C117.P$1, R115.P$1
unnamed: C214.NEG, J204.1, R212.P$1, R216.P$1
unnamed: C111.NEG, D103.A, IC101.8
unnamed: C114.POS, IC101.6
unnamed: C6.POS, R3.P$2, U602.5
unnamed: C101.P$2, C103.P$2, C104.P$1
unnamed: D3.A, R4.P$2, R5.P$1, U1.6
unnamed: D3.C, D4.A, U1.7
unnamed: C108.NEG, R104.P$2
unnamed: J103.1, R101.P$2, R102.P$2
unnamed: C107.NEG, R103.P$2
unnamed: D101.AC2, D102.C, IC101.2, R103.P$1, R105.P$1, R108.P$1
unnamed: D101.AC1, D103.C, IC101.3, R104.P$1, R106.P$1, R109.P$2
unnamed: R107.P$1, R108.P$2, R109.P$1
unnamed: D102.A, IC101.1, VR101.CCW, VR101.WIP
unnamed: R110.P$1, VR101.CW
unnamed: C111.POS, R110.P$2
unnamed: D4.C, R5.P$2, R6.P$1
unnamed: C102.P$2, C105.P$2, C106.P$1
unnamed: C3.NEG, R4.P$1
unnamed: C4.POS, R6.P$2, U502.5
unnamed: C110.NEG, R106.P$2
unnamed: D602.12, U602.18
unnamed: C109.NEG, R105.P$2
unnamed: D602.13, U602.17
unnamed: D602.14, U602.16
unnamed: D602.15, U602.15
unnamed: D602.16, U602.14
unnamed: D602.17, U602.13
unnamed: D602.18, U602.12
unnamed: D602.19, U602.11
unnamed: C215.P$1, R211.P$1, VR202.CCW
unnamed: R610.P$1, R611.P$2, U602.7
unnamed: R609.P$1, R610.P$2, U602.8
unnamed: R611.P$1, U602.6
unnamed: C5.NEG, R1.P$1
unnamed: C216.P$1, R212.P$2, VR202.CW
unnamed: R214.P$1, VR203.WIP
unnamed: C215.P$2, C216.P$2, R213.P$2, VR202.WIP
unnamed: C218.P$2, R216.P$2
unnamed: C217.P$1, R215.P$1
unnamed: C219.P$1, R213.P$1, R214.P$2, U201.2
unnamed: C214.POS, IC201.6
unnamed: C201.P$1, J201.2
unnamed: C201.P$2, C203.P$2, C204.P$1
unnamed: C203.P$1, C207.POS, J201.3, R201.P$1
unnamed: C204.P$2, C208.POS, J201.1, R202.P$1
unnamed: C208.NEG, R204.P$2
unnamed: J203.1, R201.P$2, R202.P$2
unnamed: C207.NEG, R203.P$2
unnamed: R207.P$1, R208.P$2, R209.P$1
unnamed: C211.NEG, D203.A, IC201.8
unnamed: D202.A, IC201.1, VR201.CCW, VR201.WIP
unnamed: C218.P$1, VR203.CW
unnamed: C217.P$2, VR203.CCW
unnamed: R210.P$1, VR201.CW
unnamed: C211.POS, R210.P$2
unnamed: C202.P$1, J202.2
unnamed: C202.P$2, C205.P$2, C206.P$1
unnamed: C205.P$1, C209.POS, J202.3
unnamed: C206.P$2, C210.POS, J202.1
unnamed: C210.NEG, R206.P$2
unnamed: C209.NEG, R205.P$2
unnamed: D201.AC2, D202.C, IC201.2, R203.P$1, R205.P$1, R208.P$1
unnamed: D201.AC1, D203.C, IC201.3, R204.P$1, R206.P$1, R209.P$2
unnamed: C219.P$2, C220.POS, R211.P$2, R215.P$2, U201.6
unnamed: C314.NEG, J304.1, R312.P$1, R316.P$1
unnamed: C315.P$1, R311.P$1, VR302.CCW
unnamed: C316.P$1, R312.P$2, VR302.CW
unnamed: R314.P$1, VR303.WIP
unnamed: C315.P$2, C316.P$2, R313.P$2, VR302.WIP
unnamed: C318.P$2, R316.P$2
unnamed: C317.P$1, R315.P$1
unnamed: C319.P$1, R313.P$1, R314.P$2, U301.2
unnamed: C314.POS, IC301.6
unnamed: C301.P$1, J301.2
unnamed: C301.P$2, C303.P$2, C304.P$1
unnamed: C303.P$1, C307.POS, J301.3, R301.P$1
unnamed: C304.P$2, C308.POS, J301.1, R302.P$1
unnamed: C308.NEG, R304.P$2
unnamed: J303.1, R301.P$2, R302.P$2
unnamed: C307.NEG, R303.P$2
unnamed: R307.P$1, R308.P$2, R309.P$1
unnamed: C311.NEG, D303.A, IC301.8
unnamed: D302.A, IC301.1, VR301.CCW, VR301.WIP
unnamed: C318.P$1, VR303.CW
unnamed: C317.P$2, VR303.CCW
unnamed: R310.P$1, VR301.CW
unnamed: C311.POS, R310.P$2
unnamed: C302.P$1, J302.2
unnamed: C302.P$2, C305.P$2, C306.P$1
unnamed: C305.P$1, C309.POS, J302.3
unnamed: C306.P$2, C310.POS, J302.1
unnamed: C310.NEG, R306.P$2
unnamed: C309.NEG, R305.P$2
unnamed: D301.AC2, D302.C, IC301.2, R303.P$1, R305.P$1, R308.P$1
unnamed: D301.AC1, D303.C, IC301.3, R304.P$1, R306.P$1, R309.P$2
unnamed: C319.P$2, C320.POS, R311.P$2, R315.P$2, U301.6
unnamed: C414.NEG, J404.1, R412.P$1, R416.P$1
unnamed: C415.P$1, R411.P$1, VR402.CCW
unnamed: C416.P$1, R412.P$2, VR402.CW
unnamed: R414.P$1, VR403.WIP
unnamed: C415.P$2, C416.P$2, R413.P$2, VR402.WIP
unnamed: C418.P$2, R416.P$2
unnamed: C417.P$1, R415.P$1
unnamed: C419.P$1, R413.P$1, R414.P$2, U401.2
unnamed: C414.POS, IC401.6
unnamed: C401.P$1, J401.2
unnamed: C401.P$2, C403.P$2, C404.P$1
unnamed: C403.P$1, C407.POS, J401.3, R401.P$1
unnamed: C404.P$2, C408.POS, J401.1, R402.P$1
unnamed: C408.NEG, R404.P$2
unnamed: J403.1, R401.P$2, R402.P$2
unnamed: C407.NEG, R403.P$2
unnamed: R407.P$1, R408.P$2, R409.P$1
unnamed: C411.NEG, D403.A, IC401.8
unnamed: D402.A, IC401.1, VR401.CCW, VR401.WIP
unnamed: C418.P$1, VR403.CW
unnamed: C417.P$2, VR403.CCW
unnamed: R410.P$1, VR401.CW
unnamed: C411.POS, R410.P$2
unnamed: C402.P$1, J402.2
unnamed: C402.P$2, C405.P$2, C406.P$1
unnamed: C405.P$1, C409.POS, J402.3
unnamed: C406.P$2, C410.POS, J402.1
unnamed: C410.NEG, R406.P$2
unnamed: C409.NEG, R405.P$2
unnamed: D401.AC2, D402.C, IC401.2, R403.P$1, R405.P$1, R408.P$1
unnamed: D401.AC1, D403.C, IC401.3, R404.P$1, R406.P$1, R409.P$2
unnamed: C419.P$2, C420.POS, R411.P$2, R415.P$2, U401.6
unnamed: R505.P$2, U501.3
unnamed: C501.P$1, R501.P$1, R502.P$1, R503.P$1, R504.P$1, R506.P$2, U501.2
unnamed: C505.P$1, FB501.P$2, J501.1
unnamed: C3.POS, C502.NEG, D501.AC1, D501.AC2, FB501.P$1, R508.P$1
unnamed: D502.12, U502.18
unnamed: D502.13, U502.17
unnamed: D502.14, U502.16
unnamed: D502.15, U502.15
unnamed: D502.16, U502.14
unnamed: D502.17, U502.13
unnamed: D502.18, U502.12
unnamed: D502.19, U502.11
unnamed: R510.P$1, R511.P$2, U502.7
unnamed: R509.P$1, R510.P$2, U502.8
unnamed: C501.P$2, R507.P$2, U501.6
unnamed: C502.POS, R506.P$1, R507.P$1
unnamed: R511.P$1, U502.6
unnamed: J701.1, R702.P$2
unnamed: J701.3, R701.P$2
unnamed: D701.A, R703.P$2
PREOUT: C114.NEG, J104.1, R112.P$1, R116.P$1
VCC: C2.P$1, C112.P$1, C121.P$1, C212.P$1, C221.P$1, C312.P$1, C321.P$1, C412.P$1, C421.P$1, C503.P$1, C603.P$1, C701.POS, D101.POS, D201.POS, D301.POS, D401.POS, D501.POS, D502.1, D502.2, D502.3, D502.4, D502.5, D502.6, D502.7, D502.8, D502.9, D502.10, D601.POS, D602.1, D602.2, D602.3, D602.4, D602.5, D602.6, D602.7, D602.8, D602.9, D602.10, IC101.7, IC201.7, IC301.7, IC401.7, R701.P$1, R703.P$1, U1.8, U101.7, U201.7, U301.7, U401.7, U501.7, U502.3, U601.7, U602.3
VNEG: C1.P$2, C113.P$1, C122.P$2, C213.P$1, C222.P$2, C313.P$1, C322.P$2, C413.P$1, C422.P$2, C504.P$2, C604.P$2, C702.NEG, D101.NEG, D201.NEG, D301.NEG, D401.NEG, D501.NEG, D601.NEG, IC101.4, IC201.4, IC301.4, IC401.4, R702.P$1, U1.4, U101.4, U201.4, U301.4, U401.4, U501.4, U601.4

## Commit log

2016-12-16 Adding initial commit of design files.
    [baxandall.brd, baxandall.sch]
2016-12-19 Moving to unified board design, adding datasheets.
    [baxandall.brd, baxandall.sch]
2016-12-20 A couple more bits done up.
    [baxandall.brd, baxandall.sch]
2016-12-20 Some initial routing
    one input, one output, placeholders for more.
    [unified.brd, unified.sch]
2016-12-20 A few tweaks.
    Forgot that it needs to run right-to-left.
    Added standoffs and some silk legending.
    [unified.brd, unified.sch]
2016-12-22 Capacitor update
    sourced & created a bunch of caps.
    pushed components around more & better.
    [unified.brd, unified.sch]
2016-12-23 Conforming parts on BOM for ordering.
    verified mouser & SFe part #s.
    [unified.brd, unified.sch]
2016-12-24 Duplicated input channels.
    [unified.brd, unified.sch]
2016-12-25 Assigning net classes, second summing channel.
    [unified.brd, unified.sch]
2016-12-26 Channels routed...
    [unified.brd, unified.sch]
2016-12-26 Keeping moving.
    Calculated preamp R-strings.
    Tried for the bargraphs...jusy is still out...
    Added peak tracker for meter circuit.
    [led-driver.ods, preamp-gains.ods, unified.brd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]
2016-12-30 Possibly complete?
    doublechecked all IC footprints.
    Routed the peak detector & found 1uf caps for it.
    [unified.brd, unified.sch]
2017-01-02 More touchups.
    Doublechecked rotary switch direction and values.
    Added some dimension lines.
    [unified.brd, unified.sch]
2017-01-04 Adding part numbers to some off-PCB parts.
2017-01-30 Adding unified BOM.
    [unified.csv]
2017-01-30 Some updates.
    -More BOM detail
    -SVG for temp panel.
    -Few more dimensions on board.
    -Tweaking preamp gains on rotpot boards.
    [preamp-gains.ods, unified.brd, unified.csv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]
2017-02-10 Many changes from checkplots.
    Some footprints were incorrect. Library, board & schem all updated.
    [unified.brd, unified.sch]
2017-02-11 Peppered the board with ground stitch vias.
    [unified.brd, unified.sch]
2017-02-17 Board touchups before gerbers.
    [unified.brd, unified.sch]
2017-03-17 Notes from assembly
    -Recalc'd preamp gains for actual resistors.
    -added panel SVG & PDF files.
    [preamp-gains.ods]
2017-04-05 Removing dead-end design files, adding gerbers.
    [baxandall.brd, baxandall.sch, led-driver.ods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]
2017-04-06 Amended readme.
    [unified.sch]

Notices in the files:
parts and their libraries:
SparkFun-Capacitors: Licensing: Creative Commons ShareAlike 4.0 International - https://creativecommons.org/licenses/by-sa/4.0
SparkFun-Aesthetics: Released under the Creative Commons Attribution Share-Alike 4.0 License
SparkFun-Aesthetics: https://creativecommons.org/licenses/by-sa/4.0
